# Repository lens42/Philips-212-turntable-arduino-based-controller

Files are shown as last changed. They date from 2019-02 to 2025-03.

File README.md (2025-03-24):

# Philips-212-turntable-arduino-based-controller
A controller upgrade for the classic Philips 212 Hi-Fi turntable. Replaces all touch switch, motor control, and auto-off functions with an Arduino Uno clone
Files include Arduino sketch and KiCad files
Details at:  https://lensprojects.wordpress.com/2019/01/08/philips-212-turntable-controller-upgrade/

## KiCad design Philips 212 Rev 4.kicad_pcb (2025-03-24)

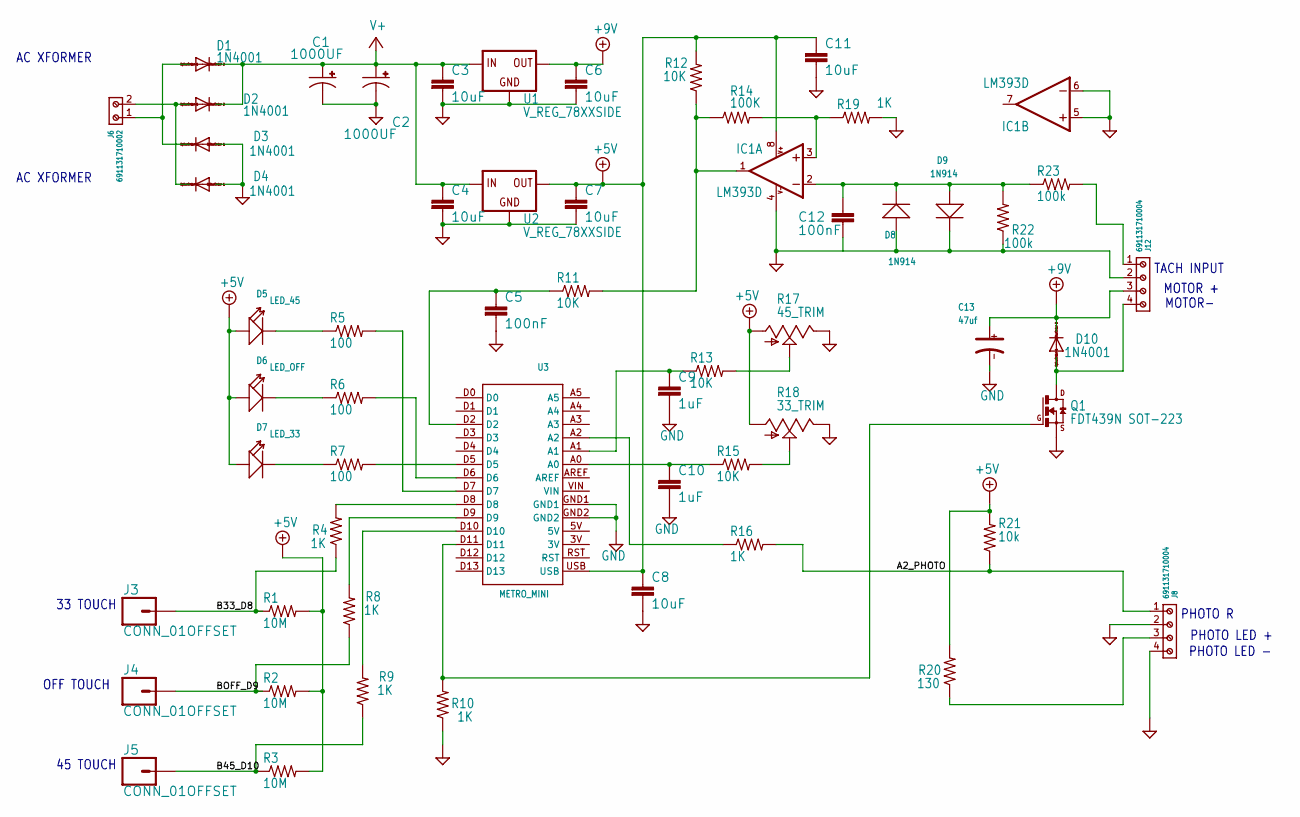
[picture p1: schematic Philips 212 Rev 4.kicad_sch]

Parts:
C1, C2: 1000UF; CAPPAD1700W60L1040D500P
C3, C4, C6, C7, C8, C11: 10uF; 1206
C5, C12: 100nF; 0805
C9, C10: 1uF; 1206
C13: 47uf; AVX-D
D1, D2, D3, D4, D10: 1N4001; DO41-10
D5: LED_45; LED2-2.54-D5.0MM
D6: LED_OFF; LED2-2.54-D5.0MM
D7: LED_33; LED2-2.54-D5.0MM
D8, D9: 1N914; DO-41
IC1: LM393D; SO08
J3, J4, J5: CONN_01OFFSET; 1X01_OFFSET
J6: 691131710002
J8, J12: 691131710004
Q1: FDT439N SOT-223; SOT-223
R1, R2, R3: 10M; M1206
R4, R8, R9, R10, R16, R19: 1K; M1206
R5, R6, R7: 100; M1206
R11, R12, R13, R15: 10K; M1206
R14: 100K; M1206
R17: 45_TRIM; PH212_POT
R18: 33_TRIM; PH212_POT
R20: 130; M1206
R21: 10k; M1206
R22, R23: 100k; M1206
U1, U2: V_REG_78XXSIDE; 78XXL
U3: METRO_MINI

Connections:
+5V: C7.1, C8.1, C11.1, D5.+, D6.+, D7.+, IC1.8 (V+), R1.2, R2.2, R3.2, R12.2, R17.1 (A), R18.1 (A), R20.2, R21.2, U2.OUT, U3.USB
+9V: C6.1, C13.+, D10.C, J12.3, U1.OUT
A0: R15.2, R18.2 (S)
A0N: C10.1, R15.1, U3.A0
A1: R13.2, R17.2 (S)
A1N: C9.1, R13.1, U3.A1
A2_PHOTO: J8.1, R16.2, R21.1
B33_D8: J3.1, R1.1, R4.1
B45_D10: J5.1, R3.1, R9.1
BOFF_D9: J4.1, R2.1, R8.1
CIN+: IC1.3 (+IN), R14.2, R19.1
CIN-: C12.1, D8.2 (-), D9.1 (+), IC1.2 (-IN), R22.2, R23.1
CMPOUT: IC1.1 (OUT), R11.2, R12.1, R14.1
D2: C5.1, R11.1, U3.D2
D8: R4.2, U3.D8
D9: R8.2, U3.D9
D10: R9.2, U3.D10
D10_GATE: Q1.1 (G), R10.2, U3.D11
GND: C1.2 (-), C2.2 (-), C3.2, C4.2, C5.2, C6.2, C7.2, C8.2, C9.2, C10.2, C11.2, C12.2, C13.-, D3.A, D4.A, D8.1 (+), D9.2 (-), IC1.4 (V-), IC1.5 (+IN), IC1.6 (-IN), J8.2, J8.4, J12.2, Q1.3 (S), R10.1, R17.3 (E), R18.3 (E), R19.2, R22.1, U1.GND, U2.GND, U3.GND1, U3.GND2
L33: D7.-, R7.1
L45: D5.-, R5.1
L45_D7: R5.2, U3.D7
LOFF: D6.-, R6.1
LOFF_D6: R6.2, U3.D6
MOTR-: D10.A, J12.4, Q1.2 (D), Q1.4 (D)
unnamed: R7.2, U3.D5
unnamed: R16.1, U3.A2
unnamed: J8.3, R20.1
unnamed: D1.A, D3.C, J6.1
unnamed: D2.A, D4.C, J6.2
TACH: J12.1, R23.2
V+: C1.1 (+), C2.1 (+), C3.1, C4.1, D1.C, D2.C, U1.IN, U2.IN

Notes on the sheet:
OFF TOUCH
PHOTO R
AC XFORMER
MOTOR +
MOTOR-
33 TOUCH
TACH INPUT
45 TOUCH
PHOTO LED -
PHOTO LED +

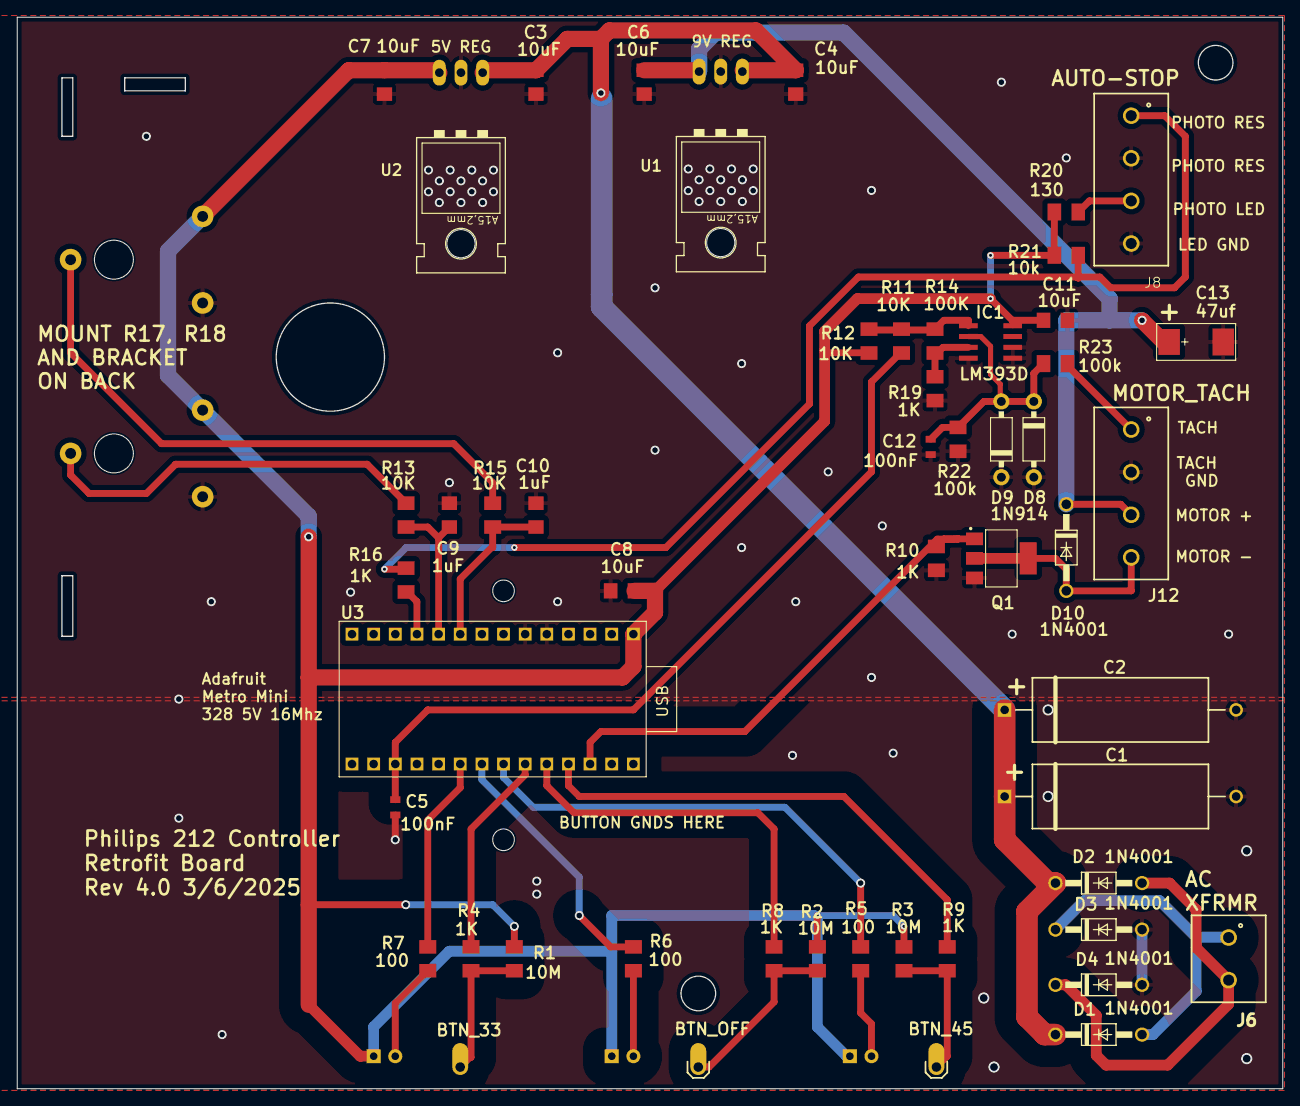
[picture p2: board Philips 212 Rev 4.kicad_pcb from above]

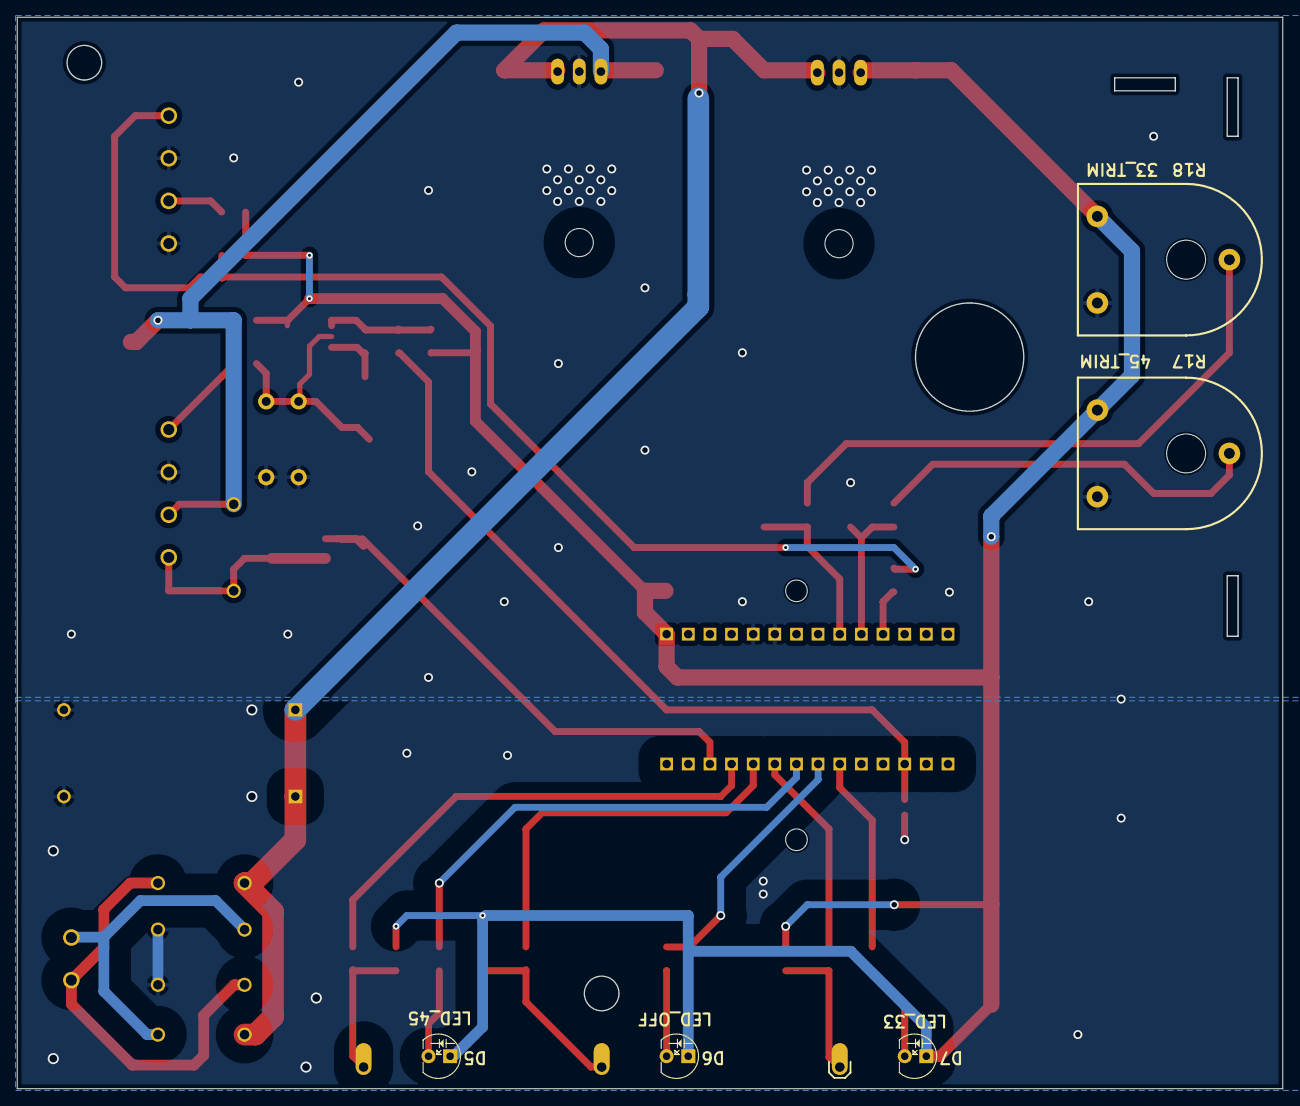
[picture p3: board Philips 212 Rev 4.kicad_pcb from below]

Board: 2 copper layers, 148.5 x 125.7 mm, 61 parts (6 on the bottom side), 32 nets.

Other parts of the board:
@HOLE0, @HOLE1, @HOLE2, @HOLE3: (no value)

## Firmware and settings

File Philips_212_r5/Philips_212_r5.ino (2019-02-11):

#define LEDOFF 6    // "OFF" LED drive output, LOW = on
#define LED33 5     // "33" LED drive output, LOW = on
#define LED45 7     // "45" LED drive output, LOW = on
#define BTNOFF 9    // "OFF" touch button input  
#define BTN33 8     // "33" touch button input
#define BTN45 10    // "45" touch button input
#define trimpot_33 A0  // analog input from trim pot to fine tune 33 RPM
#define trimpot_45 A1   // analog inpit from trim pot to fine tune 45 RPM
#define OPTO A2         // analog input from auto off photo resistor 

byte stateOFF = LOW;      // current state of LEDOFF output, start LEDOFF low (on) at power up
byte readingOFF= LOW;    // current reading from BTNOFF input, start BTNOFF low at power up
byte previousOFF = LOW;   // the previous reading from the BTN input, start low at power up

byte state33 = HIGH;      //start 33 RPM off at power up
byte reading33 = HIGH;           
byte previous33 = HIGH;    

byte state45 = HIGH;      //start 45 RPM off at power up
byte reading45 = HIGH;           
byte previous45 = HIGH;

int v_trim_45;            //45 RPM fine trim pot value
int v_trim_33;            //33 RPM fine trim pot value
int v_photo;               //auto-off photo sensor value
int photo_trip;             //threshold for auto-off sensing
int trim_offset;            //offset fine trim reading so center rotation = 0

byte tach_in = 2;         //input pin for tach output from motor
byte PWM_out = 11;        //PWM drive output to motor
int t_diff;              //difference between set and target period
int t_set;               //Tach period target value for the currently active RPM
int t_set_33;            //Tach period target value for 33RPM
int t_set_45;            //Tach period target value for 45RPM
int t_err_range;         //sets gain of motor control loop
int n_PWM;               //PWM motor drive    
int n_offset;
volatile unsigned long t_per;
unsigned long microseconds; 
    

// the following variables are long's because the time, measured in miliseconds,
// will quickly become a bigger number than can be stored in an int.
long timeOFF = 0;         // the last time the OFF touch botton changed state
long time33 = 0;          // the last time the 33 touch botton changed state
long time45 = 0;          // the last time the 45 touch botton changed state
long debounce = 10;   // debounce time (ms) can be short because OFF, 33, and 45 states latch until a different button is pressed
                    
void setup()
{
  pinMode(BTNOFF, INPUT);  //set up OFF, 33, and 45 buttons
  pinMode(BTN33, INPUT);
  pinMode(BTN45, INPUT);
  pinMode(LED45, OUTPUT);  //set up OFF, 33, and 45 indicator LEDs
  pinMode(LED33, OUTPUT);
  pinMode(LEDOFF, OUTPUT);
  pinMode(tach_in, INPUT);
  pinMode(PWM_out, OUTPUT);
  attachInterrupt(0, tachometer, FALLING); // set external interrupt for tachometer period measurment
  //Serial.begin(115200);   //run when troubleshooting
  
  t_set_33 = 24650;         //target period for 33RPM. Set by trying values while measuring turntable with a separate tachometer
  
  t_set_45 = 17700;         //target period for 45RPM. Set by trying values while measuring turntable with a separate tachometer
  
  t_per = 50000;            //start with long per to ensure startup
  t_err_range = 7000;       //maps to PWM output to set gain. Lower number equals higher gain. Set while watching PWM output on oscilloscope. Set to highest values that does not result in oscillation pulse width.
  n_offset = 127-43;        // PWM output that drives motor at 33.3 RPM. Measured to get approximately correct output when t_diff is 0
  trim_offset = 512;        // offset fine adjust readings so mid rotation = 0
  photo_trip = 800;         // threshold for end-of-record auto-off photo sensor
                            
}

/* switch
 * 
 * Each time the input pin goes from LOW to HIGH (e.g. because of a push-button
 * press), the corrosponding output pin goes low and the other two go high. 
 * Repeated button presses of the same button do nothing. A different button must be pressed to change state.
 * There's a minimum delay between toggles to debounce the circuit (i.e. to ignore
 * noise) 
 *
 * David A. Mellis with modifications by L. Sherman (2/2019) for interlock mechanism
 * 21 November 2006
 */

void loop()

{  
    
// trouble-shooting serial print parameters
//Serial.print(t_per);
//Serial.print(" ");
//Serial.print(t_diff);
//Serial.print(" ");
//Serial.print(v_trim_33);
//Serial.print(" ");
//Serial.print(v_trim_45);
//Serial.print (" ");
//Serial.print (t_set);
//Serial.print (" ");
//Serial.print (n_PWM);
//Serial.print (" ");
//Serial.print (v_photo);
//Serial.println();

v_trim_45 = analogRead (trimpot_45);
v_trim_33 = analogRead (trimpot_33);
v_photo = analogRead (OPTO);

  // if the input just went from LOW and HIGH and we've waited long enough
  // to ignore any noise on the circuit, drive the output pin low and the other two outputs high and remember
  // the time
  
  // code for "OFF" button and LED
  
  readingOFF = digitalRead(BTNOFF);
   if (readingOFF == LOW && millis() - timeOFF > debounce) {
    if (stateOFF == HIGH)
    {stateOFF = LOW;
      state33 = HIGH;     //turn off OFF and 45 LEDS
      state45 = HIGH;}    //turn off OFF and 33 LEDS
      
    else
      stateOFF = LOW;

    timeOFF = millis();     
  }
  digitalWrite(LEDOFF, stateOFF);
  previousOFF = readingOFF;

  
  // code for "33 RPM" button and LED
  reading33 = digitalRead(BTN33);

  if (reading33 == LOW && millis() - time33 > debounce) {
    if (state33 == HIGH)
       {stateOFF = HIGH;
      state33 = LOW;
      state45 = HIGH;
     
       }
    else 
      state33 = LOW;
    time33 = millis();
         
  }

 if (state33 == LOW) {
  t_set = t_set_33 + v_trim_33 - trim_offset;
  } 

  digitalWrite(LED33, state33);

  previous33 = reading33;
  
  
  // code for "45 RPM" button and LED
reading45 = digitalRead(BTN45);

  if (reading45 == LOW && millis() - time45 > debounce) {
    if (state45 == HIGH)
       {stateOFF = HIGH;
      state33 = HIGH;
      state45 = LOW;
     
      }
    
    else 
      state45 = LOW;
    time45 = millis();
        
  }

  if (state45 == LOW) {
  t_set = t_set_45 + v_trim_45 - trim_offset; 
  }

  digitalWrite(LED45, state45);
  previous45 = reading45;

//end of "45 RPM" code

if (v_photo > photo_trip) // When the tonearm reaches the record end, the photo resistor is interrupted and the OFF state is set
{     stateOFF = LOW;     // off state, OFF LED on
      state33 = HIGH;     // turn off OFF and 45 LEDS
      state45 = HIGH;}
 
// read period from tachometer and control motor
 t_per = constrain(t_per, 5000, 50000);
 t_diff = t_per - t_set;
 n_PWM = map(t_diff, t_err_range, -t_err_range, 255, 0);
 n_PWM = n_PWM - n_offset;
 n_PWM = constrain(n_PWM, 0, 255);

if (stateOFF == LOW) analogWrite (PWM_out, 0);    //hold motor off during OFF state
else analogWrite(PWM_out, n_PWM);                 //else drive motor with PWM output
 
}

//Determine time between pulses from tachometer
void tachometer() 
{    
    t_per = micros() - microseconds;
microseconds = micros();
}

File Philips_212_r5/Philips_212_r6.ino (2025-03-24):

#define LED_OFF 6         // "OFF" LED drive output, LOW = on

#define LED_33 5          // "33" LED drive output, LOW = on

#define LED_45 7          // "45" LED drive output, LOW = on

#define BTN_OFF 9         // "OFF" touch button input

#define BTN_33 8          // "33" touch button input

#define BTN_45 10         // "45" touch button input

#define TRIM_POT_33 A0    // Analog input from trim pot to fine tune 33 RPM

#define TRIM_POT_45 A1    // Analog input from trim pot to fine tune 45 RPM

#define OPTO A2           // Analog input from auto-off photo resistor

#define TACH_IN 2         // Input pin for tach output from motor

#define PWM_OUT 11        // PWM drive output to motor

#define DEBOUNCE_TIME 10  // Debounce time in milliseconds

#define PHOTO_TRIP 700    // Threshold for end-of-record auto-off photo sensor

#define TRIM_OFFSET 512   // Offset fine trim reading so center rotation = 0 (512)

#define T_SET_33 24000    // Target period for 33 RPM (was 24650)

#define T_SET_45 16550    // Target period for 45 RPM (was 17700)

#define T_ERR_RANGE 7000  // Sets gain of motor control loop

#define N_OFFSET 84       // PWM output that drives motor at 33.3 RPM

byte stateOff = LOW;      // Current state of LED_OFF output, start LED_OFF low (on) at power up

byte readingOff = LOW;    // Current reading from BTN_OFF input, start BTN_OFF low at power up

byte state33 = HIGH;      // Start 33 RPM off at power up

byte reading33 = HIGH;

byte state45 = HIGH;      // Start 45 RPM off at power up

byte reading45 = HIGH;

int trim45;               // 45 RPM fine trim pot value

int trim33;               // 33 RPM fine trim pot value

int photoValue;           // Auto-off photo sensor value

int t_set;                // Tach period target value for the currently active RPM

long pwmValue = 0;        // PWM outout to motor

long tachDiff = 0;        // Tacho difference to compensate

volatile unsigned long tachPeriod;

unsigned long tachMicroseconds;

long lastDebounceTimeOff = 0;  // Last time the OFF touch button changed state

long lastDebounceTime33 = 0;   // Last time the 33 touch button changed state

long lastDebounceTime45 = 0;   // Last time the 45 touch button changed state

void setup() {

  Serial.begin(115200);   //run when troubleshooting

  pinMode(BTN_OFF, INPUT);  // Set up OFF, 33, and 45 buttons

  pinMode(BTN_33, INPUT);

  pinMode(BTN_45, INPUT);

  pinMode(LED_45, OUTPUT);  // Set up OFF, 33, and 45 indicator LEDs

  pinMode(LED_33, OUTPUT);

  pinMode(LED_OFF, OUTPUT);

  pinMode(TACH_IN, INPUT);

  pinMode(PWM_OUT, OUTPUT);

  attachInterrupt(digitalPinToInterrupt(TACH_IN), tachometer, FALLING); // Set external interrupt for tachometer period measurement

  tachPeriod = 50000;  // Start with long period to ensure startup

} // setup

void loop() {

  trim45 = analogRead(TRIM_POT_45);

  trim33 = analogRead(TRIM_POT_33);

  photoValue = analogRead(OPTO);

  // Code for "OFF" button and LED

  readingOff = digitalRead(BTN_OFF);

  if (readingOff == LOW && millis() - lastDebounceTimeOff > DEBOUNCE_TIME) {

    stateOff = LOW;

    state33 = HIGH;  // Turn off OFF and 45 LEDs

    state45 = HIGH;  // Turn off OFF and 33 LEDs

    lastDebounceTimeOff = millis();

  } // if readingOff..

  digitalWrite(LED_OFF, stateOff);

  // Code for "33 RPM" button and LED

  reading33 = digitalRead(BTN_33);

  if (reading33 == LOW && millis() - lastDebounceTime33 > DEBOUNCE_TIME) {

    stateOff = HIGH;

    state33 = LOW;

    state45 = HIGH;

    lastDebounceTime33 = millis();

  } // if reading33..

  if (state33 == LOW) {

    t_set = T_SET_33 + trim33 - TRIM_OFFSET;

  } // if state33..

  digitalWrite(LED_33, state33);

  // Code for "45 RPM" button and LED

  reading45 = digitalRead(BTN_45);

  if (reading45 == LOW && millis() - lastDebounceTime45 > DEBOUNCE_TIME) {

    stateOff = HIGH;

    state33 = HIGH;

    state45 = LOW;        

    lastDebounceTime45 = millis();

  } // if reading45..

  if (state45 == LOW) {

    t_set = T_SET_45 + trim45 - TRIM_OFFSET;

  } // if state45..

  digitalWrite(LED_45, state45);

  // When the tonearm reaches the record end, the photo resistor is interrupted and the OFF state is set

  if (photoValue > PHOTO_TRIP) {

    stateOff = LOW;  // Off state, OFF LED on

    state33 = HIGH;  // Turn off OFF and 45 LEDs

    state45 = HIGH;

  } // if photoValue..

  // Read period from tachometer and control motor

  tachPeriod = constrain(tachPeriod, 5000, 50000);

  tachDiff = tachPeriod - t_set;  // Corrected calculation

  pwmValue = map(tachDiff, T_ERR_RANGE, -T_ERR_RANGE, 255, 0); // T_ERR_RANGE = 7000

  pwmValue = pwmValue - N_OFFSET; // N_OFFSET = 84 is pwm value for speed 33

  pwmValue = constrain(pwmValue, 0, 255);

  if (stateOff == LOW) {

    analogWrite(PWM_OUT, 0);  // Hold motor off during OFF state

  } else {

    analogWrite(PWM_OUT, pwmValue);  // Else drive motor with PWM output

    //Serial.println(pwmValue);

  } // if stateOff..

  Serial.println(photoValue);

} // loop

// Determine time between pulses from tachometer

void tachometer() {

  tachPeriod = micros() - tachMicroseconds;

  tachMicroseconds = micros();

} // tachometer

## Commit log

2025-03-24 Add files via upload
    Rev 6 fixes a 45 RPM startup issues and some sloppy code
    [Philips_212_r6.ino]
2025-03-24 Delete Phiips 212 r2.brd
    old version
    [Phiips 212 r2.brd]
2025-03-24 Delete Phiips 212 r3.brd
    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
    [Phiips 212 r3.brd]
2025-03-24 Delete Phiips 212 r2.sch
    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
    [Phiips 212 r2.sch]
2025-03-24 Delete Phiips 212 r3.sch
    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
    [Phiips 212 r3.sch]
